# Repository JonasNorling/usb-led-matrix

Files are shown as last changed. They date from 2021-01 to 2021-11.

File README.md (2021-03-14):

A USB connected LED matrix
==========================

This is a quick holidays project from 2020/2021. It is a 8×8 SMD LED matrix board with a STM32G4 and USB-C connector.

What it does is up to the software but currently I use it to display CPU load on my PC. When not connected to a USB host it displays a calm animation.

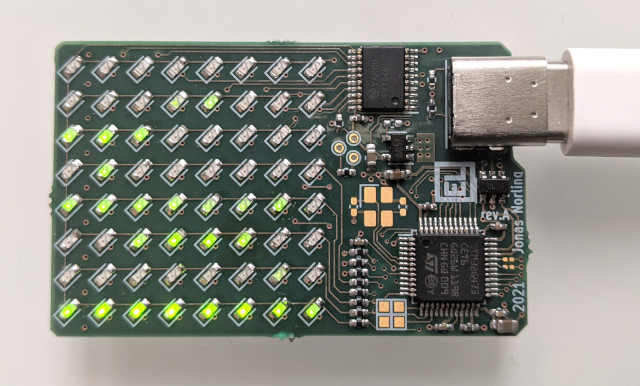
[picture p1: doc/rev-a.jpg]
Board front view rev.A board


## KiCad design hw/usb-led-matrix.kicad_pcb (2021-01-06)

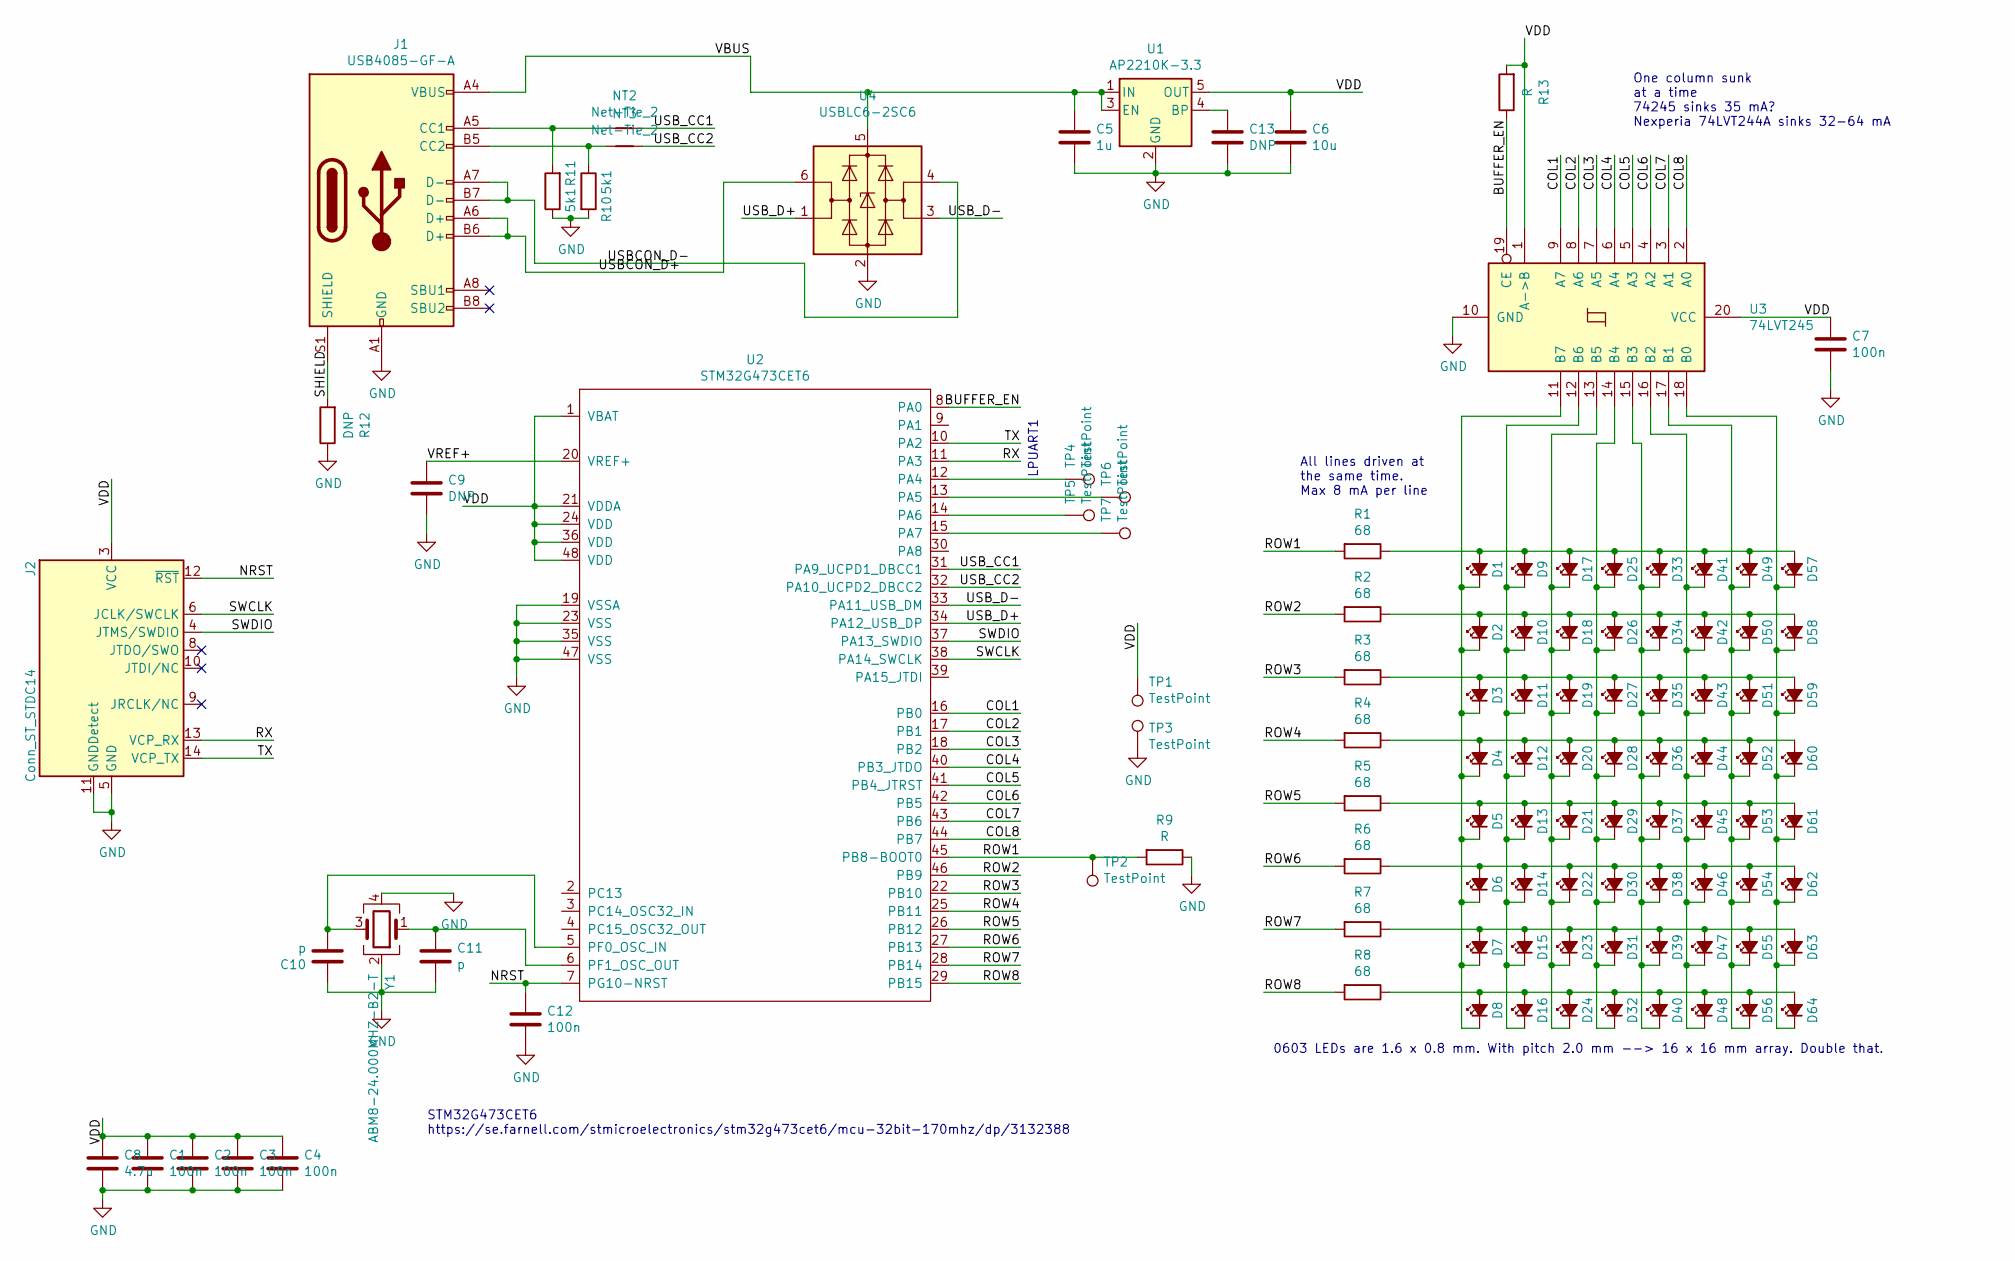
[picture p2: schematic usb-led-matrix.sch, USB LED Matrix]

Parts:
C1, C2, C3, C4, C7, C12: 100n; C_0402_1005Metric_Pad0.74x0.62mm_HandSolder
C5: 1u; C_0603_1608Metric_Pad1.08x0.95mm_HandSolder
C6: 10u; C_0603_1608Metric_Pad1.08x0.95mm_HandSolder
C8: 4.7u; C_0603_1608Metric_Pad1.08x0.95mm_HandSolder
C9, C13: DNP; C_0402_1005Metric_Pad0.74x0.62mm_HandSolder
C10, C11: p; C_0402_1005Metric_Pad0.74x0.62mm_HandSolder
D1, D2, D3, D4, D5, D6, D7, D8, D9, D10, D11, D12, D13, D14, D15, D16, D17, D18, D19, D20, D21, D22, D23, D24, D25, D26, D27, D28, D29, D30, D31, D32, D33, D34, D35, D36, D37, D38, D39, D40, D41, D42, D43, D44, D45, D46, D47, D48, D49, D50, D51, D52, D53, D54, D55, D56, D57, D58, D59, D60, D61, D62, D63, D64: LED_Small_ALT; LED_0603_1608Metric
J1: USB4085-GF-A; USB_C_Receptacle_GCT_USB4085
J2: Conn_ST_STDC14; PinHeader_2x07_P1.27mm_Vertical_SMD
NT2, NT3: Net-Tie_2; R_0201_0603Metric
R1, R2, R3, R4, R5, R6, R7, R8: 68; R_0402_1005Metric_Pad0.72x0.64mm_HandSolder
R9, R13: R; R_0402_1005Metric_Pad0.72x0.64mm_HandSolder
R10, R11: 5k1; R_0402_1005Metric_Pad0.72x0.64mm_HandSolder
R12: DNP; R_0402_1005Metric_Pad0.72x0.64mm_HandSolder
TP1, TP2, TP3: TestPoint; TestPoint_THTPad_D1.0mm_Drill0.5mm
TP4, TP5, TP6, TP7: TestPoint; TestPoint_Pad_1.0x1.0mm
U1: AP2210K-3.3; SOT-23-5
U2: STM32G473CET6; LQFP-48_7x7mm_P0.5mm
U3: 74LVT245; TSSOP-20_4.4x6.5mm_P0.65mm
U4: USBLC6-2SC6; SOT-23-6
Y1: ABM8-24.000MHZ-B2-T; Crystal_SMD_3225-4Pin_3.2x2.5mm

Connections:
/BUFFER_EN: R13.1, U2.8 (PA0), U3.19 (CE)
/COL1: U2.16 (PB0), U3.9 (A7)
/COL2: U2.17 (PB1), U3.8 (A6)
/COL3: U2.18 (PB2), U3.7 (A5)
/COL4: U2.40 (PB3_JTDO), U3.6 (A4)
/COL5: U2.41 (PB4_JTRST), U3.5 (A3)
/COL6: U2.42 (PB5), U3.4 (A2)
/COL7: U2.43 (PB6), U3.3 (A1)
/COL8: U2.44 (PB7), U3.2 (A0)
/NRST: C12.1, J2.12 (~RST), U2.7 (PG10-NRST)
/ROW1: R1.2, R9.2, TP2.1, U2.45 (PB8-BOOT0)
/ROW2: R2.2, U2.46 (PB9)
/ROW3: R3.2, U2.22 (PB10)
/ROW4: R4.2, U2.25 (PB11)
/ROW5: R5.2, U2.26 (PB12)
/ROW6: R6.2, U2.27 (PB13)
/ROW7: R7.2, U2.28 (PB14)
/ROW8: R8.2, U2.29 (PB15)
/RX: J2.13 (VCP_RX), U2.11 (PA3)
/SHIELD: J1.S1 (SHIELD), R12.2
/SWCLK: J2.6 (JCLK/SWCLK), U2.38 (PA14_SWCLK)
/SWDIO: J2.4 (JTMS/SWDIO), U2.37 (PA13_SWDIO)
/TX: J2.14 (VCP_TX), U2.10 (PA2)
/USBCON_D+: J1.A6 (D+), J1.B6 (D+), U4.6 (I/O1)
/USBCON_D-: J1.A7 (D-), J1.B7 (D-), U4.4 (I/O2)
/USB_CC1: NT2.2, U2.31 (PA9_UCPD1_DBCC1)
/USB_CC2: NT3.2, U2.32 (PA10_UCPD2_DBCC2)
/USB_D+: U2.34 (PA12_USB_DP), U4.1 (I/O1)
/USB_D-: U2.33 (PA11_USB_DM), U4.3 (I/O2)
/VBUS: C5.1, J1.A4 (VBUS), J1.A9 (VBUS), J1.B4 (VBUS), J1.B9 (VBUS), U1.1 (IN), U1.3 (EN), U4.5 (VBUS)
/VDD: C1.1, C2.1, C3.1, C4.1, C6.1, C7.1, C8.1, J2.3 (VCC), R13.2, TP1.1, U1.5 (OUT), U2.1 (VBAT), U2.21 (VDDA), U2.24 (VDD), U2.36 (VDD), U2.48 (VDD), U3.1 (A->B), U3.20 (VCC)
/VREF+: C9.1, U2.20 (VREF+)
GND: C1.2, C2.2, C3.2, C4.2, C5.2, C6.2, C7.2, C8.2, C9.2, C10.1, C11.2, C12.2, C13.2, J1.A1 (GND), J1.A12 (GND), J1.B1 (GND), J1.B12 (GND), J2.5 (GND), J2.7 (GND), J2.11 (GNDDetect), R9.1, R10.2, R11.1, R12.1, TP3.1, U1.2 (GND), U2.19 (VSSA), U2.23 (VSS), U2.35 (VSS), U2.47 (VSS), U3.10 (GND), U4.2 (GND), Y1.2, Y1.4
unnamed: C10.2, U2.5 (PF0_OSC_IN), Y1.3
unnamed: C11.1, U2.6 (PF1_OSC_OUT), Y1.1
unnamed: C13.1, U1.4 (BP)
unnamed: D1.1 (K), D2.1 (K), D3.1 (K), D4.1 (K), D5.1 (K), D6.1 (K), D7.1 (K), D8.1 (K), U3.11 (B7)
unnamed: D1.2 (A), D9.2 (A), D17.2 (A), D25.2 (A), D33.2 (A), D41.2 (A), D49.2 (A), D57.2 (A), R1.1
unnamed: D9.1 (K), D10.1 (K), D11.1 (K), D12.1 (K), D13.1 (K), D14.1 (K), D15.1 (K), D16.1 (K), U3.12 (B6)
unnamed: D2.2 (A), D10.2 (A), D18.2 (A), D26.2 (A), D34.2 (A), D42.2 (A), D50.2 (A), D58.2 (A), R2.1
unnamed: D3.2 (A), D11.2 (A), D19.2 (A), D27.2 (A), D35.2 (A), D43.2 (A), D51.2 (A), D59.2 (A), R3.1
unnamed: D4.2 (A), D12.2 (A), D20.2 (A), D28.2 (A), D36.2 (A), D44.2 (A), D52.2 (A), D60.2 (A), R4.1
unnamed: D5.2 (A), D13.2 (A), D21.2 (A), D29.2 (A), D37.2 (A), D45.2 (A), D53.2 (A), D61.2 (A), R5.1
unnamed: D6.2 (A), D14.2 (A), D22.2 (A), D30.2 (A), D38.2 (A), D46.2 (A), D54.2 (A), D62.2 (A), R6.1
unnamed: D7.2 (A), D15.2 (A), D23.2 (A), D31.2 (A), D39.2 (A), D47.2 (A), D55.2 (A), D63.2 (A), R7.1
unnamed: D8.2 (A), D16.2 (A), D24.2 (A), D32.2 (A), D40.2 (A), D48.2 (A), D56.2 (A), D64.2 (A), R8.1
unnamed: D17.1 (K), D18.1 (K), D19.1 (K), D20.1 (K), D21.1 (K), D22.1 (K), D23.1 (K), D24.1 (K), U3.13 (B5)
unnamed: D25.1 (K), D26.1 (K), D27.1 (K), D28.1 (K), D29.1 (K), D30.1 (K), D31.1 (K), D32.1 (K), U3.14 (B4)
unnamed: D33.1 (K), D34.1 (K), D35.1 (K), D36.1 (K), D37.1 (K), D38.1 (K), D39.1 (K), D40.1 (K), U3.15 (B3)
unnamed: D41.1 (K), D42.1 (K), D43.1 (K), D44.1 (K), D45.1 (K), D46.1 (K), D47.1 (K), D48.1 (K), U3.16 (B2)
unnamed: D49.1 (K), D50.1 (K), D51.1 (K), D52.1 (K), D53.1 (K), D54.1 (K), D55.1 (K), D56.1 (K), U3.17 (B1)
unnamed: D57.1 (K), D58.1 (K), D59.1 (K), D60.1 (K), D61.1 (K), D62.1 (K), D63.1 (K), D64.1 (K), U3.18 (B0)
unnamed: J1.A5 (CC1), NT2.1, R11.2
unnamed: J1.B5 (CC2), NT3.1, R10.1
unnamed: TP4.1, U2.12 (PA4)
unnamed: TP5.1, U2.14 (PA6)
unnamed: TP6.1, U2.13 (PA5)
unnamed: TP7.1, U2.15 (PA7)

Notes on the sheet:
All lines driven at the same time. Max 8 mA per line
One column sunk at a time 74245 sinks 35 mA? Nexperia 74LVT244A sinks 32-64 mA
STM32G473CET6 https://se.farnell.com/stmicroelectronics/stm32g473cet6/mcu-32bit-170mhz/dp/3132388
0603 LEDs are 1.6 x 0.8 mm. With pitch 2.0 mm --> 16 x 16 mm array. Double that.
LPUART1

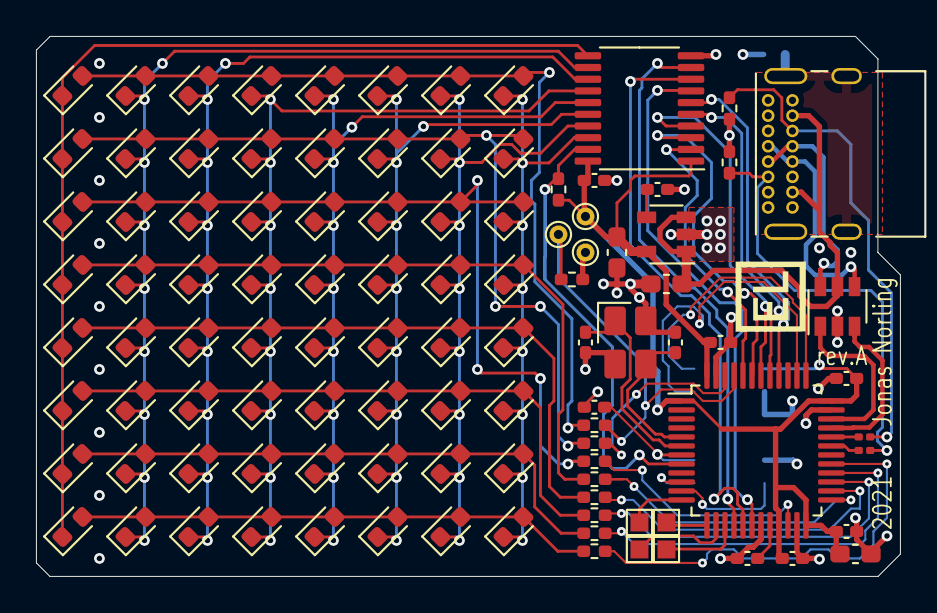
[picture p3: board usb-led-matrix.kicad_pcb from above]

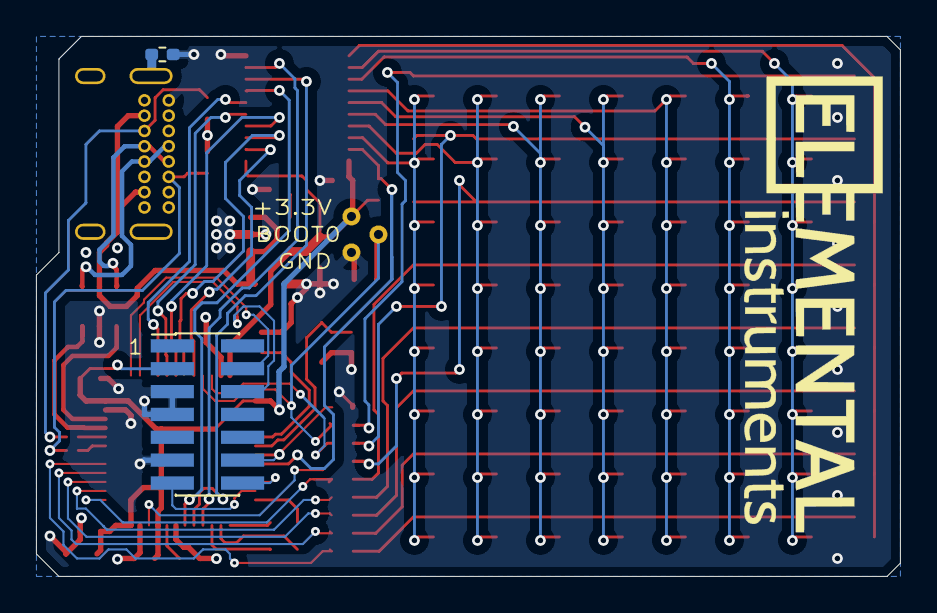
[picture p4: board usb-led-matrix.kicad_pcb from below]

Board: 4 copper layers, 48.0 x 30.0 mm, 106 parts (2 on the bottom side), 58 nets.

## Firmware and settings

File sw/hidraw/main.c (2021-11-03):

/*
 * User-space driver for the USB-LED-matrix,
 * showing CPU load.
 */

#include <stdio.h>
#include <fcntl.h>
#include <stdbool.h>
#include <stdint.h>
#include <unistd.h>
#include <time.h>
#include <sys/ioctl.h>
#include <linux/hidraw.h>
#include <string.h>
#include <stdlib.h>
#include <assert.h>
#include <dirent.h>

#define MAX_CPUS 32
#define ROWS 8
#define COLS 8
#define SHOW_CPUS ROWS
#define HZ 10
#define PWM_STEPS 8
#define UPDATE_TIME_US (1000000 / HZ)

#define MIN(x, y) ((x) < (y) ? (x) : (y))
#define MAX(x, y) ((x) > (y) ? (x) : (y))

// USB HID report
__attribute__((packed)) struct report {
    uint8_t report_no;
    uint8_t led_state[64];
};

struct stat_info {
    int cpus;
    struct {
        int jiffies;
    } cpu[MAX_CPUS];
};


static void print_help(const char *progname)
{
    printf(
        "Usage: %s [<hidraw device>]\n",
        progname);
}

static void get_stat(int fd, struct stat_info *stat_info)
{
    // This function is a segmentation fault waiting to happen

    char buf[4096] = "";
    int res = pread(fd, buf, sizeof(buf), 0);
    if (res < 0) {
        perror("Failed to read /proc/stat");
        return;
    }

    const char *pt = buf;

    // Skip first line (cpu)
    pt = strchr(pt, '\n');
    if (pt) pt++;

    // Parse individual cpu lines
    while (pt) {
        int cpu, user, nice, system, idle, iowait;
        res = sscanf(pt, "cpu%d %d %d %d %d %d",
                     &cpu, &user, &nice, &system, &idle, &iowait);
        if (res != 6 || cpu >= MAX_CPUS) {
            // We've gone past the cpu<n> lines
            break;
        }
        stat_info->cpu[cpu].jiffies = user + nice + system + iowait;
        stat_info->cpus = cpu + 1;
        pt = strchr(pt, '\n');
        if (pt) pt++;
    }
}

static int open_device(const char *node)
{
    int fd = open(node, O_WRONLY);
    if (fd < 0) {
        return fd;
    }

    char name[256] = "";
    int res = ioctl(fd, HIDIOCGRAWNAME(sizeof(name)), name);
    if (res < 0) {
        perror("ioctl failed");
        return res;
    }

    printf("Opened hidraw device %s: %s\n", node, name);

    if (strcmp(name, "Elemental Instruments usb-led-matrix")) {
        close(fd);
        fd = -1;
    }

    return fd;
}

static int64_t now_us(void)
{
    struct timespec ts;
    clock_gettime(CLOCK_MONOTONIC, &ts);
    return ts.tv_sec * 1000000 + ts.tv_nsec / 1000;
}

static void sleep_us(int64_t us)
{
    if (us < 0) {
        return;
    }
    const struct timespec ts = {
        .tv_sec = us / 1000000000,
        .tv_nsec = us * 1000,
    };
    int res = nanosleep(&ts, NULL);
    if (res < 0) {
        perror("Nanosleep failed");
    }
}

static int hid_name_filter(const struct dirent *dirent)
{
    return !strncmp("hidraw", dirent->d_name, 6);
}

static int find_device(void)
{
    int usb_fd = -1;
    struct dirent **namelist = NULL;

    int count = scandir("/dev", &namelist, hid_name_filter, versionsort);
    if (count < 0) {
        perror("Scandir failed");
        return -1;
    }

    for (int i = 0; i < count; i++) {
        char full_name[PATH_MAX];
        snprintf(full_name, PATH_MAX, "/dev/%s", namelist[i]->d_name);
        int fd = open_device(full_name);
        free(namelist[i]);
        if (fd >= 0) {
            usb_fd = fd;
            break;
        }
    }

    free(namelist);
    return usb_fd;
}

static int find_and_open_device(const char *device_name)
{
    int usb_fd = -1;

    if (device_name) {
        usb_fd = open_device(device_name);
        if (usb_fd < 0) {
            perror("Unable to open hidraw device");
            return 1;
        }
    }
    else {
        // Try to find the right device
        for (int i = 0; ; i++) {
            usb_fd = find_device();
            if (usb_fd != -1) {
                break;
            }
            if (i == 0) {
                printf("Waiting for USB device...\n");
            }
            sleep(1);
        }
    }

    return usb_fd;
}

int main(int argc, const char *argv[])
{
    int64_t target_time;
    int usb_fd = -1;
    const char *device_name = NULL;

    if (argc > 2) {
        print_help(argv[0]);
        return 1;
    }
    if (argc > 1) {
        device_name = argv[1];
    }

    usb_fd = find_and_open_device(device_name);
    if (usb_fd < 0) {
        return 1;
    }

    int stat_fd = open("/proc/stat", O_RDONLY);
    if (stat_fd < 0) {
        perror("Error opening /proc/stat");
        return 1;
    }

    /*
     * Put up a static image
     */
    struct report report = { .led_state = {
        0, 1, 1, 1, 1, 1, 1, 0,
        1, 1, 1, 2, 2, 1, 1, 1,
        1, 1, 3, 4, 4, 3, 1, 1,
        1, 2, 4, 8, 8, 4, 2, 1,
        1, 2, 4, 8, 8, 4, 2, 1,
        1, 1, 3, 4, 4, 3, 1, 1,
        1, 1, 1, 2, 2, 1, 1, 1,
        0, 1, 1, 1, 1, 1, 1, 0,
    }};

    int res = write(usb_fd, &report, sizeof(report));
    if (res < 0) {
        fprintf(stderr, "Write returned %d\n", res);
        perror("Failed to write report");
        return 1;
    }
    sleep_us(900000);

    /*
     * Output CPU load
     */
    struct stat_info stat_info = {};
    struct stat_info last_stat_info = {};
    get_stat(stat_fd, &last_stat_info);

    target_time = now_us();
    while (true) {
        get_stat(stat_fd, &stat_info);
        int jiffies[SHOW_CPUS] = {};
        for (int i = 0; i < stat_info.cpus; i++) {
            jiffies[i % SHOW_CPUS] += stat_info.cpu[i].jiffies - last_stat_info.cpu[i].jiffies;
        }
        last_stat_info = stat_info;

        struct report report = {};
        const int jiffies_per_tick = ((stat_info.cpus / SHOW_CPUS) * HZ);
        for (int row = 0; row < ROWS; row++) {
            const float led_count = (float)jiffies[row] * COLS / jiffies_per_tick;
            for (int col = 0; col < COLS; col++) {
                const float brightness = PWM_STEPS * (led_count - col);
                report.led_state[(row * 8) + col] = MAX(MIN(brightness, 8), 0);
            }
        }

        int res = write(usb_fd, &report, sizeof(report));
        if (res < 0) {
            fprintf(stderr, "Write returned %d\n", res);
            perror("Failed to write report");
            return 1;
        }

        target_time += UPDATE_TIME_US;
        sleep_us(target_time - now_us());
    }

    close(usb_fd);
    close(stat_fd);
    return 0;
}

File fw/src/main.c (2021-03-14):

#include <zephyr.h>
#include <logging/log.h>

#include "led_matrix.h"
#include "usbdev.h"

#if CONFIG_SOC_STM32G474XX
#include <stm32g4xx_ll_crs.h>
#endif

LOG_MODULE_REGISTER(main);

/*
 * Enable clock recovery to make USB work with internal oscillator
 */
static void enable_crs()
{
#if CONFIG_CLOCK_STM32_PLL_SRC_HSI
    __HAL_RCC_CRS_CLK_ENABLE();
    LL_CRS_DeInit();
    LL_CRS_SetSyncDivider(LL_CRS_SYNC_DIV_1);
    LL_CRS_SetSyncPolarity(LL_CRS_SYNC_POLARITY_RISING);
    LL_CRS_SetSyncSignalSource(LL_CRS_SYNC_SOURCE_USB);
    LL_CRS_SetReloadCounter(__LL_CRS_CALC_CALCULATE_RELOADVALUE(48000000,1000));
    LL_CRS_SetFreqErrorLimit(LL_CRS_ERRORLIMIT_DEFAULT);
    LL_CRS_SetHSI48SmoothTrimming(LL_CRS_HSI48CALIBRATION_DEFAULT);
    LL_CRS_EnableAutoTrimming();
    LL_CRS_EnableFreqErrorCounter();
#endif
}

/*
 * Configure brown-out reset at a reasonable voltage level
 */
static void configure_bor()
{
#if CONFIG_SOC_STM32G474XX
    FLASH_OBProgramInitTypeDef ob = {};
    HAL_FLASHEx_OBGetConfig(&ob);

    if ((ob.USERConfig & FLASH_OPTR_BOR_LEV_Msk) != FLASH_OPTR_BOR_LEV_3) {
        LOG_INF("User option bytes: %08x", ob.USERConfig);
        static const FLASH_OBProgramInitTypeDef ob_write = {
            .OptionType = OPTIONBYTE_USER,
            .USERType = OB_USER_BOR_LEV,
            .USERConfig = OB_BOR_LEVEL_3,
        };
        if (HAL_FLASH_Unlock() != HAL_OK) {
            LOG_ERR("Failed to unlock flash");
        }
        if (HAL_FLASH_OB_Unlock() != HAL_OK) {
            LOG_ERR("Failed to unlock OB");
        }
        if (HAL_FLASHEx_OBProgram((FLASH_OBProgramInitTypeDef*)&ob_write) != HAL_OK) {
            LOG_ERR("Failed to program option bytes");
        }
        if (HAL_FLASH_OB_Lock() != HAL_OK) {
            LOG_ERR("Failed to lock OB");
        }
        if (HAL_FLASH_Lock() != HAL_OK) {
            LOG_ERR("Failed to lock flash");
        }
    }
#endif
}

void main(void)
{
#if CONFIG_SOC_STM32G474XX
    HAL_DBGMCU_EnableDBGSleepMode();
    HAL_DBGMCU_EnableDBGStopMode();
    HAL_DBGMCU_EnableDBGStandbyMode();
#endif

    led_matrix_init();
    enable_crs();
    configure_bor();
    usbdev_init();
    led_matrix_start();

    while (true) {
        k_sleep(K_FOREVER);
    }
}

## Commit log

2020-12-27 Script to make LED array
2020-12-29 USB-C connector
    [usb-led-matrix.sch]
2020-12-31 Schematic updates
    - TVS on USB
    - SOT23-5 vreg
    - 100n on NRST
    - SWO hooked up
    - Caps on crystal
    [usb-led-matrix.sch]
2020-12-31 Connect more USB signals
    [usb-led-matrix.sch]
2020-12-31 Four-layer board, update routing and some components
    [usb-led-matrix.kicad_pcb, usb-led-matrix.sch]
2020-12-31 Rearrange pins
    [usb-led-matrix.kicad_pcb, usb-led-matrix.sch]
2021-01-01 Update routing
    [usb-led-matrix.kicad_pcb, usb-led-matrix.sch]
2021-01-01 Use custom board
    Copied and slightly adapted from NUCLEO-G474RE.
2021-01-01 Set LEDs
2021-01-01 PCB updates
    [usb-led-matrix.kicad_pcb]
2021-01-06 Add missing KiCad libraries
2021-01-06 Fine tune PCB, silkscreen rev.A
    [usb-led-matrix.kicad_pcb, usb-led-matrix.sch]
2021-01-09 Set LED states?
2021-01-16 Fix timing in hidraw program
    [main.c]
2021-01-23 Fix bug in led_matrix.c
    [led_matrix.c]
2021-01-25 Timer interrupt controlling LEDs
2021-02-05 LED control
2021-03-14 Picture of the board
2021-05-08 Scan for right hidraw device
2021-11-03 Wait for USB device to be plugged in
